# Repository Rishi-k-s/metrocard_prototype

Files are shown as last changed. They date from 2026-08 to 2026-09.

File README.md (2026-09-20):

# MetroCard

A credit-card-sized PCB that shows real-time Kochi Metro data — a tiny, tappable transit map you can hold in your wallet.

Built by [Rishi Krishna](https://rishikrishna.com) / [Phenomi](https://phenomi.co). 

### Firmware
Checkout the metrocard [Firmware](https://github.com/Rishi-k-s/metrocard_firmware)

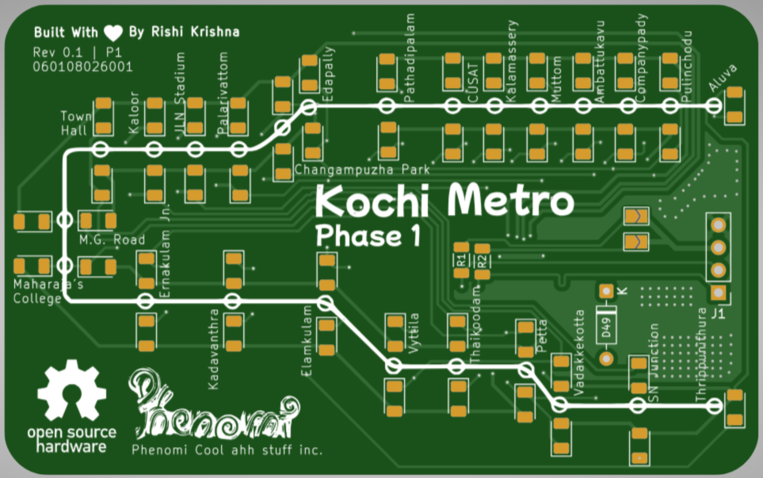
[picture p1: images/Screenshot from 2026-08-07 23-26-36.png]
Front of the card

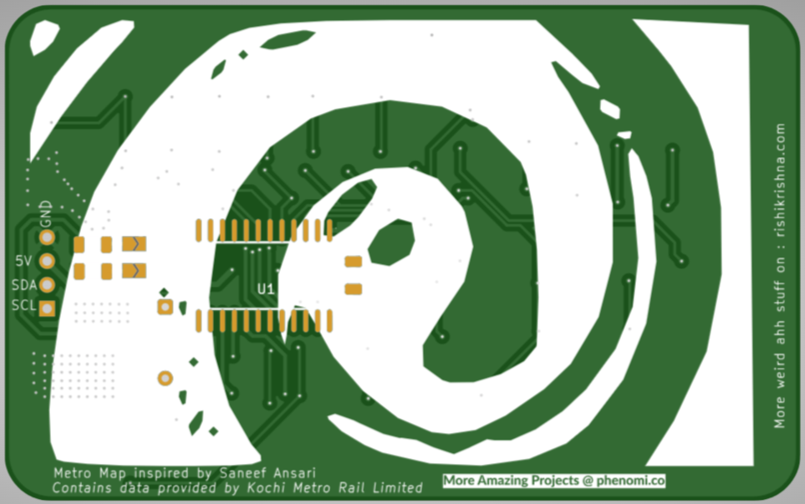
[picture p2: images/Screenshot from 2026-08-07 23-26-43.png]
Back of the card

The schematic


## About

The front silkscreen traces the full Kochi Metro **Phase 1** line, from Aluva to Thripunithura, with every station labeled. A 1206 LED sits at each of the 49 stations (`D00`–`D48`), so the map can light up to reflect train position or other live status along the line.

The back houses the electronics:

- **U1 — HT16K33** LED driver/matrix controller, addressed over **I²C**
- **J1** — 4-pin JST-EH connector breaking out `GND`, `5V`, `SDA`, `SCL`
- **JP2/JP3** — address jumpers (`A0`, `A1`) so multiple cards can share an I²C bus at different addresses
- **JP4/JP5** — I²C bus pass-through/jumpers
- Pull-up resistors and support passives for the I²C bus and driver

The card is standard credit-card dimensions, designed to be carried like any other card.

## Credits

- Metro map artwork inspired by Saneef Ansari
- Station and line data provided by Kochi Metro Rail Limited (KMRL)

## Repository contents

- `metrocard.kicad_pro` / `metrocard.kicad_pcb` / `metrocard.kicad_sch` — KiCad project, PCB layout, and schematic
- `metrocard.csv` — bill of materials
- `DRC.rpt` — latest design rule check report
- `images/` — renders/screenshots of the board
- `libs/`, `fp-lib-table`, `sym-lib-table` — local footprint/symbol library references

## Status

Revision 0.1 — first prototype (`Rev 0.1 | P1 060108026001`).

## License

Open source hardware, licensed under the [GNU GPL v3](LICENSE.md).

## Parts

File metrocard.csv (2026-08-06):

Reference | Qty | Value | DNP | Exclude from BOM | Exclude from Board | Footprint | Datasheet
C1 | 1 | 0.1uF |  |  |  |  | ~
D00,D01,D02,D03,D04,D05,D06,D7,D8,D9,D10,D11,D12,D13,D14,D15,D16,D17,D18,D19,D20,D21,D22,D23,D24,D25,D26,D27,D28,D29,D30,D31,D32,D33,D34,D35,D36,D37,D38,D39,D40,D41,D42,D43,D44,D45,D46,D47,D48 | 49 | LED |  |  |  | LED_SMD:LED_1206_3216Metric_Pad1.42x1.75mm_HandSolder | ~
D49 | 1 | 1N4148 |  |  |  | Diode_THT:D_DO-35_SOD27_P7.62mm_Horizontal | https://assets.nexperia.com/documents/data-sheet/1N4148_1N4448.pdf
J1 | 1 | Conn_01x04 |  |  |  | Connector_JST:JST_EH_B4B-EH-A_1x04_P2.50mm_Vertical | ~
JP2 | 1 | ADDR_A0 |  | Excluded from BOM |  |  | ~
JP3 | 1 | ADDR_A1 |  | Excluded from BOM |  |  | ~
JP4,JP5 | 2 | I2C2 |  | Excluded from BOM |  |  | ~
R1,R2 | 2 | 4.7K |  |  |  |  | ~
R4,R5 | 2 | 39K |  |  |  |  | ~
U1 | 1 | HT16K33A-24SOP |  |  |  | lcsc_footprints:C5444735_SOP-24_L15_4-W7_5-P1_27-LS10_4-BL

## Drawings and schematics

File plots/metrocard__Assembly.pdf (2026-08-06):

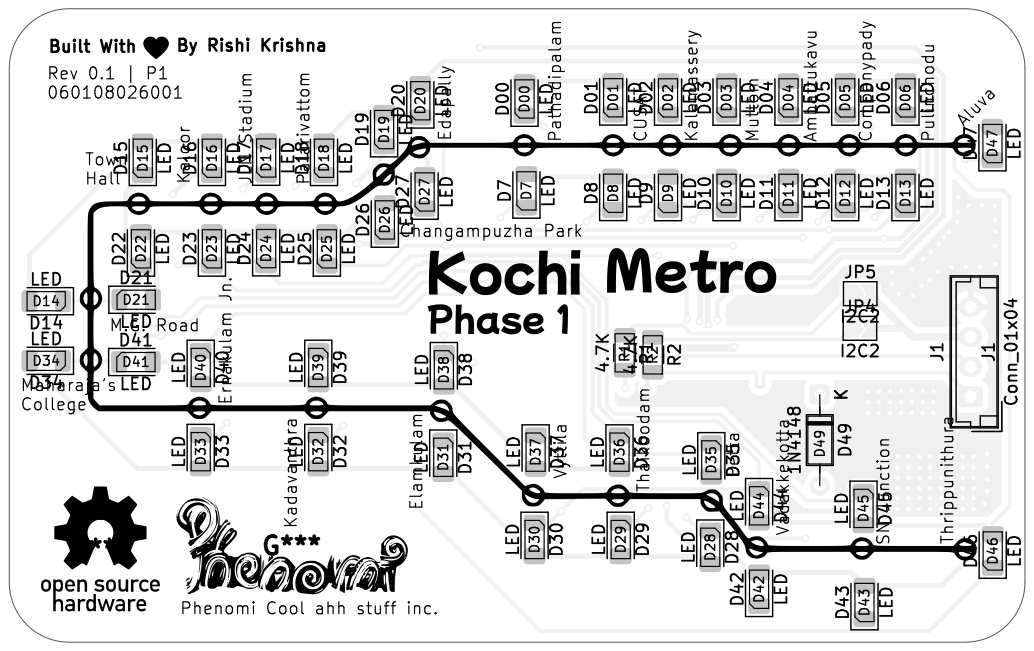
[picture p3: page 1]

SNThrippunithura Junction Vadakkekotta Petta Thaikoodam Vyttila Elamkulam Kadavanthra Ernakulam Jn. Maharaja's College M.G. Road Changampuzha Park Town Hall Kaloor JLN Stadium Palarivattom Edapally Pathadipalam CUSAT Kalamassery Muttom Ambattukavu Rev 0.1 | P1

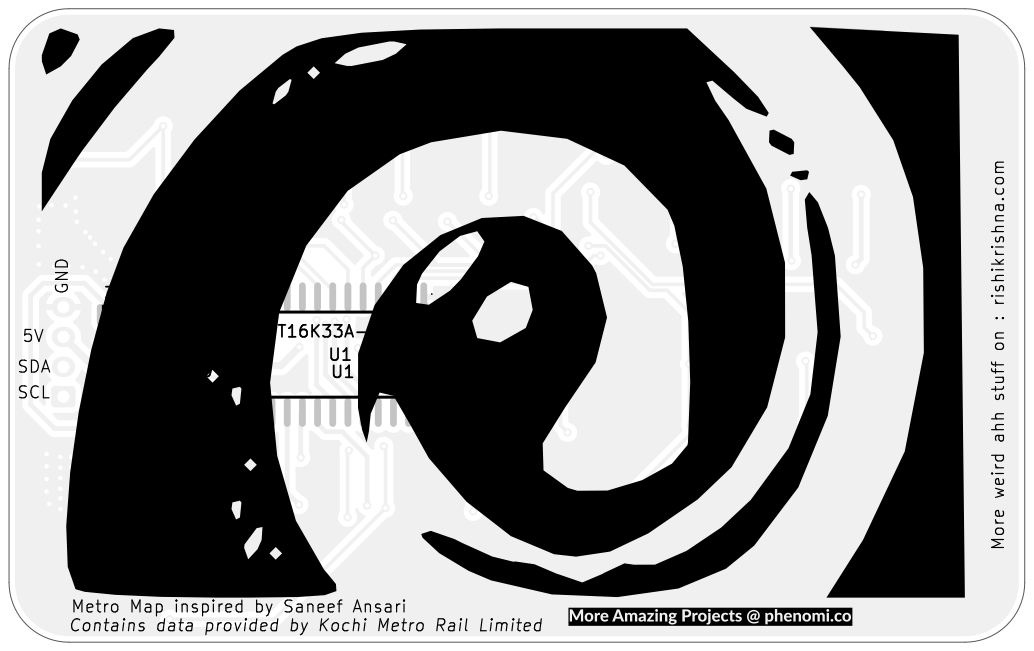
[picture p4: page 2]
SCL Contains data provided by Kochi Metro Rail Limited GND; D Date: 2026-08-06 KiCad; E.D.A. 9.0.9 Size: A4; Rev: 0.1; Id: /1 Title: Card PCB Test File: metrocard.kicad_pcb Sheet: Black; And; White; BOT Phenomi Board2Pdf:; Black; BOT -; Page 2/2; ADDR_A1 ADDR_A0; HT16K33A-24SOP U1

More weird ahh stuff on : rishikrishna.com

Metro Map inspired by Saneef Ansari 5V
SDA

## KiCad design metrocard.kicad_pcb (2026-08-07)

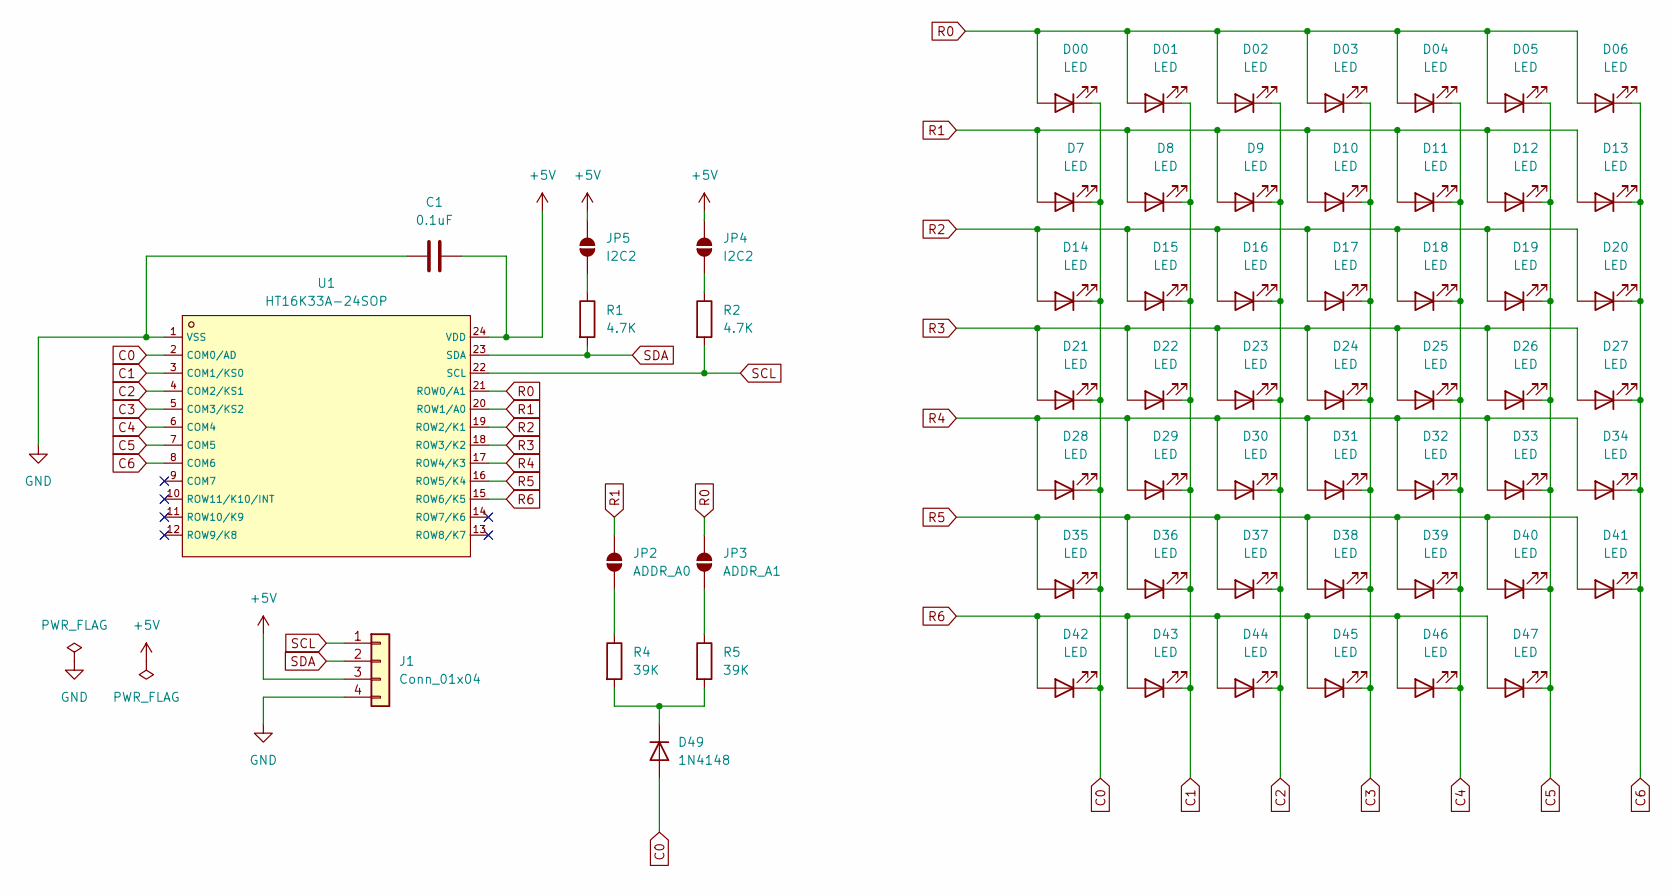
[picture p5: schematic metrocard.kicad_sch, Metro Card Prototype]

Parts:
C1: 0.1uF; C_1206_3216Metric
D00, D01, D02, D03, D04, D05, D06, D7, D8, D9, D10, D11, D12, D13, D14, D15, D16, D17, D18, D19, D20, D21, D22, D23, D24, D25, D26, D27, D28, D29, D30, D31, D32, D33, D34, D35, D36, D37, D38, D39, D40, D41, D42, D43, D44, D45, D46, D47: LED; LED_1206_3216Metric
D49: 1N4148; D_DO-35_SOD27_P7.62mm_Horizontal
J1: Conn_01x04; JST_EH_B4B-EH-A_1x04_P2.50mm_Vertical
JP2: ADDR_A0; SolderJumper-2_P1.3mm_Open_TrianglePad1.0x1.5mm
JP3: ADDR_A1; SolderJumper-2_P1.3mm_Open_TrianglePad1.0x1.5mm
JP4, JP5: I2C2; SolderJumper-2_P1.3mm_Open_TrianglePad1.0x1.5mm
R1, R2: 4.7K; R_1206_3216Metric
R4, R5: 39K; R_1206_3216Metric
U1: HT16K33A-24SOP; C5444735_SOP-24_L15_4-W7_5-P1_27-LS10_4-BL; LCSC C5444735

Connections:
+5V: C1.2, J1.3, JP4.2 (B), JP5.2 (B), U1.24 (VDD)
C0: D00.1 (K), D7.1 (K), D14.1 (K), D21.1 (K), D28.1 (K), D35.1 (K), D42.1 (K), D49.2 (A), U1.2 (COM0/AD)
C1: D01.1 (K), D8.1 (K), D15.1 (K), D22.1 (K), D29.1 (K), D36.1 (K), D43.1 (K), U1.3 (COM1/KS0)
C2: D02.1 (K), D9.1 (K), D16.1 (K), D23.1 (K), D30.1 (K), D37.1 (K), D44.1 (K), U1.4 (COM2/KS1)
C3: D03.1 (K), D10.1 (K), D17.1 (K), D24.1 (K), D31.1 (K), D38.1 (K), D45.1 (K), U1.5 (COM3/KS2)
C4: D04.1 (K), D11.1 (K), D18.1 (K), D25.1 (K), D32.1 (K), D39.1 (K), D46.1 (K), U1.6 (COM4)
C5: D05.1 (K), D12.1 (K), D19.1 (K), D26.1 (K), D33.1 (K), D40.1 (K), D47.1 (K), U1.7 (COM5)
C6: D06.1 (K), D13.1 (K), D20.1 (K), D27.1 (K), D34.1 (K), D41.1 (K), U1.8 (COM6)
GND: C1.1, J1.4, U1.1 (VSS)
unnamed: D49.1 (K), R4.2, R5.2
unnamed: JP2.1 (A), R4.1
unnamed: JP3.1 (A), R5.1
unnamed: JP4.1 (A), R2.1
unnamed: JP5.1 (A), R1.1
R0: D00.2 (A), D01.2 (A), D02.2 (A), D03.2 (A), D04.2 (A), D05.2 (A), D06.2 (A), JP3.2 (B), U1.21 (ROW0/A1)
R1: D7.2 (A), D8.2 (A), D9.2 (A), D10.2 (A), D11.2 (A), D12.2 (A), D13.2 (A), JP2.2 (B), U1.20 (ROW1/A0)
R2: D14.2 (A), D15.2 (A), D16.2 (A), D17.2 (A), D18.2 (A), D19.2 (A), D20.2 (A), U1.19 (ROW2/K1)
R3: D21.2 (A), D22.2 (A), D23.2 (A), D24.2 (A), D25.2 (A), D26.2 (A), D27.2 (A), U1.18 (ROW3/K2)
R4: D28.2 (A), D29.2 (A), D30.2 (A), D31.2 (A), D32.2 (A), D33.2 (A), D34.2 (A), U1.17 (ROW4/K3)
R5: D35.2 (A), D36.2 (A), D37.2 (A), D38.2 (A), D39.2 (A), D40.2 (A), D41.2 (A), U1.16 (ROW5/K4)
R6: D42.2 (A), D43.2 (A), D44.2 (A), D45.2 (A), D46.2 (A), D47.2 (A), U1.15 (ROW6/K5)
SCL: J1.1, R2.2, U1.22 (SCL)
SDA: J1.2, R1.2, U1.23 (SDA)

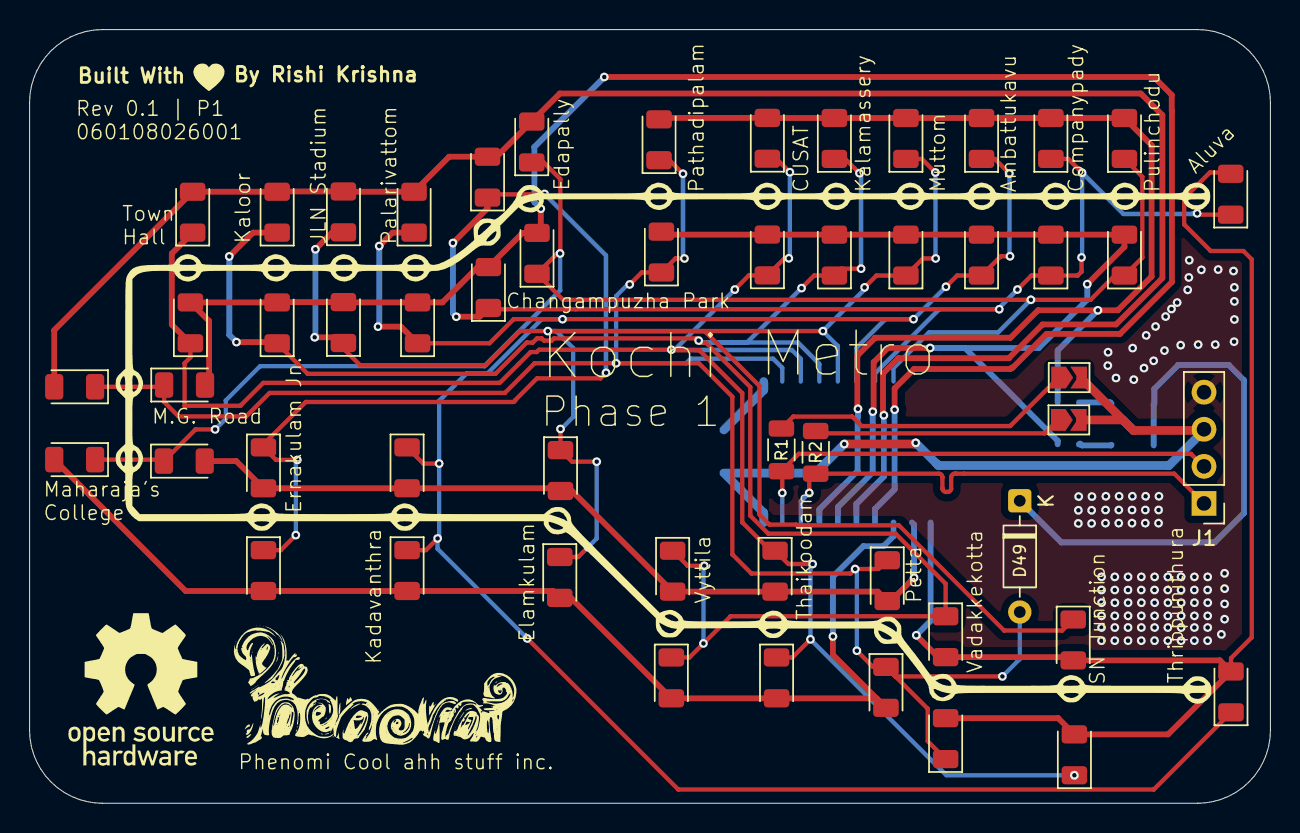
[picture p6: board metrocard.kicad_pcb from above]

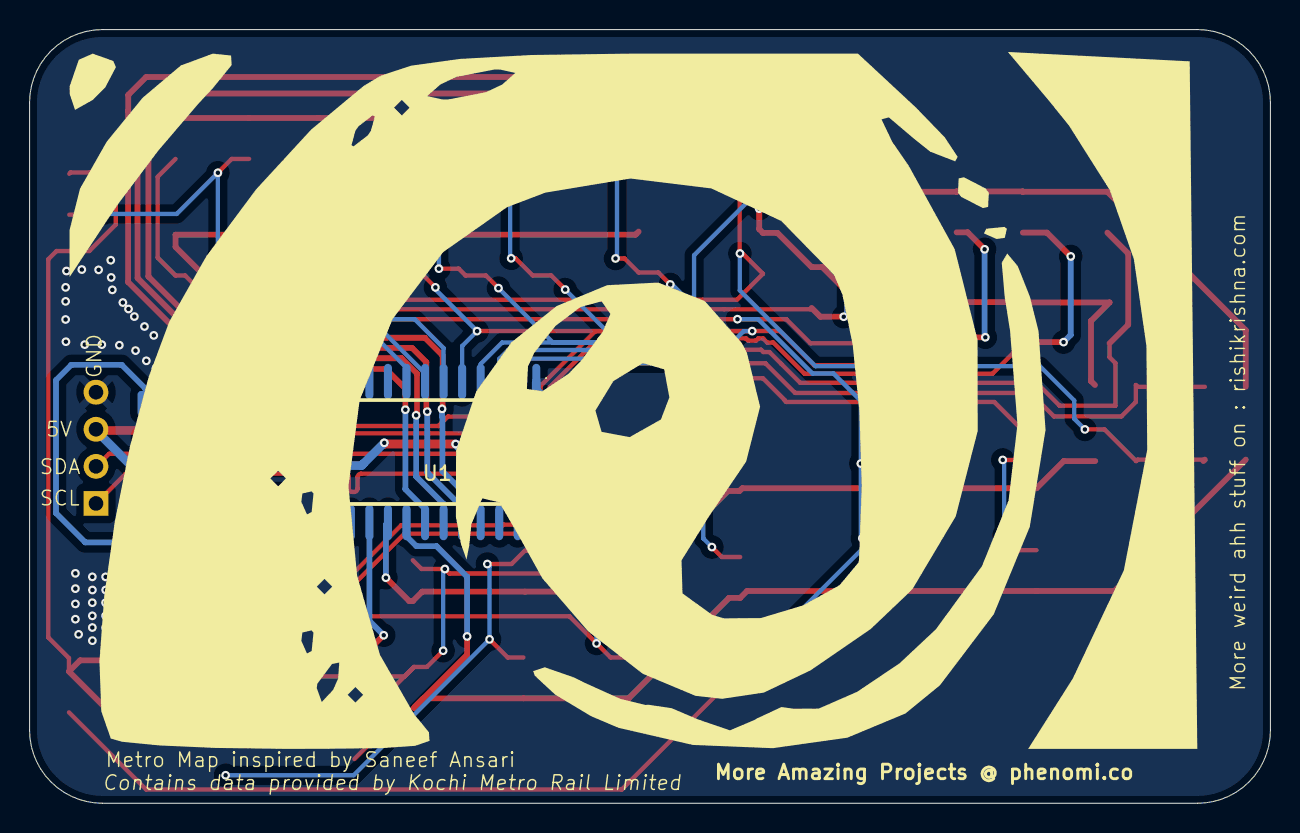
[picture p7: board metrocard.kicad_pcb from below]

Board: 2 copper layers, 85.0 x 53.0 mm, 60 parts (6 on the bottom side), 23 nets.

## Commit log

2026-08-07 added readme
    [metrocard.kicad_pcb]
2026-09-20 Update README with schematic and project details
    Added schematic image and updated project description.
